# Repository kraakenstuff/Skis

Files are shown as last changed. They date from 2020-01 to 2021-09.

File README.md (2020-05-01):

# Skis

This is smd version of Bastl Skis v1. Main differences are:

* It has skis (two sliders) vs. no skis in Bastl version
* 6HP vs. 5HP, for obvious, OCD reasons
* Range switch vs. range backside jumper (although this switch works as a jumper - instead of going from freq0 to freq1, and then from freq1 to freq2 in the second position, it goes from freq0 to freq1, and then from freq0 to freq2)
* Version 2 of Bastl Skis has decay CV input, and this one doesn't have it
* Version 1 of Bastl Skis was THT and had two sandwiched boards, and this one is SMT in one board.

Status: tested and working.

CC-BY-SA
Václav Peloušek
bastl-instruments.com

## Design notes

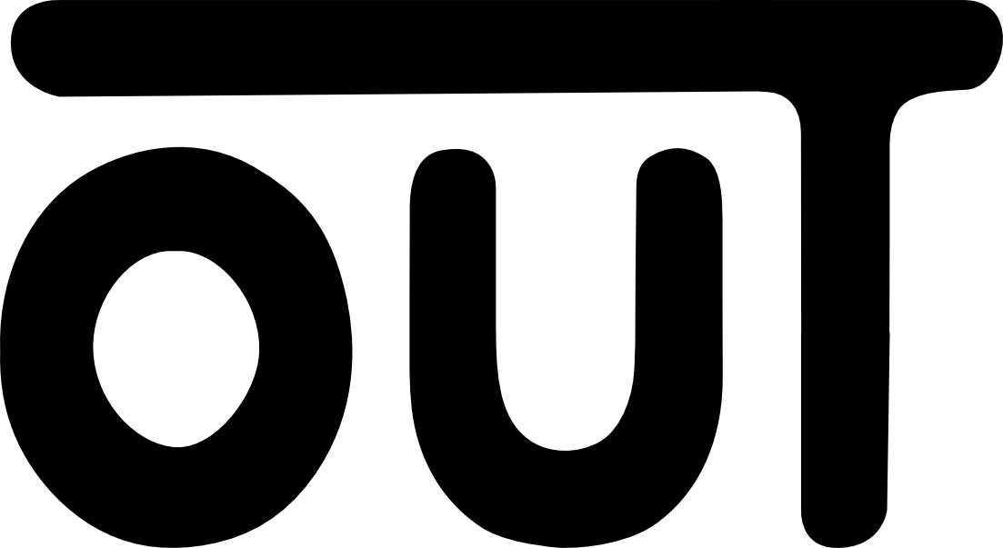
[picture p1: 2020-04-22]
art/out1.png

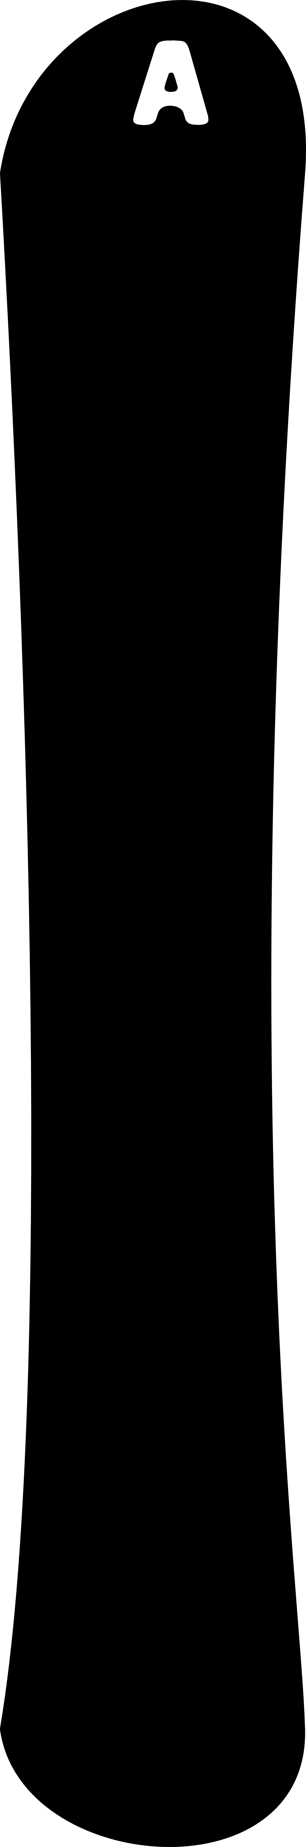
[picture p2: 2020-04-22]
art/ski_a.png

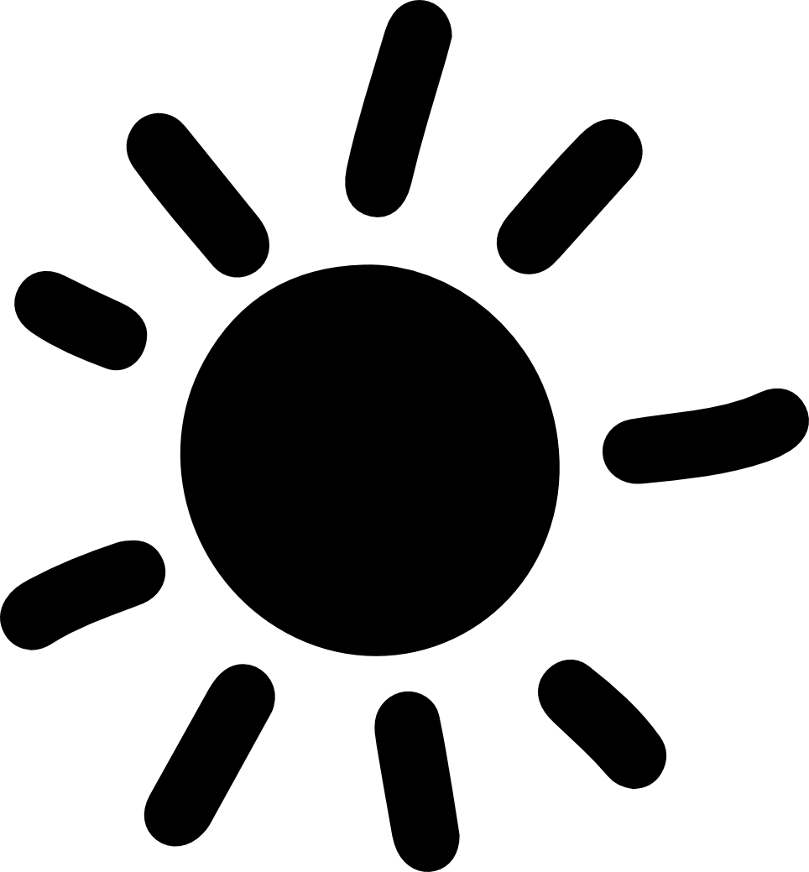
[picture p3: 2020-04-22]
art/sun.png

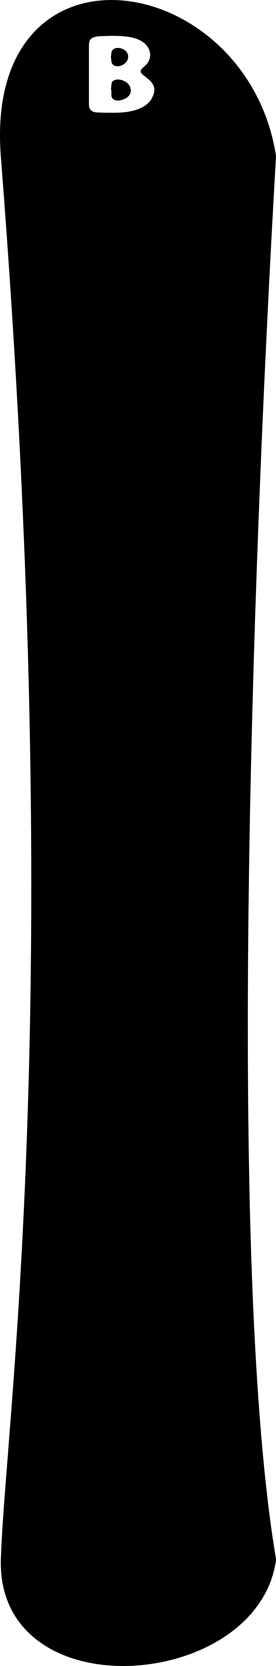
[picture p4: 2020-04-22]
art/ski_b.png

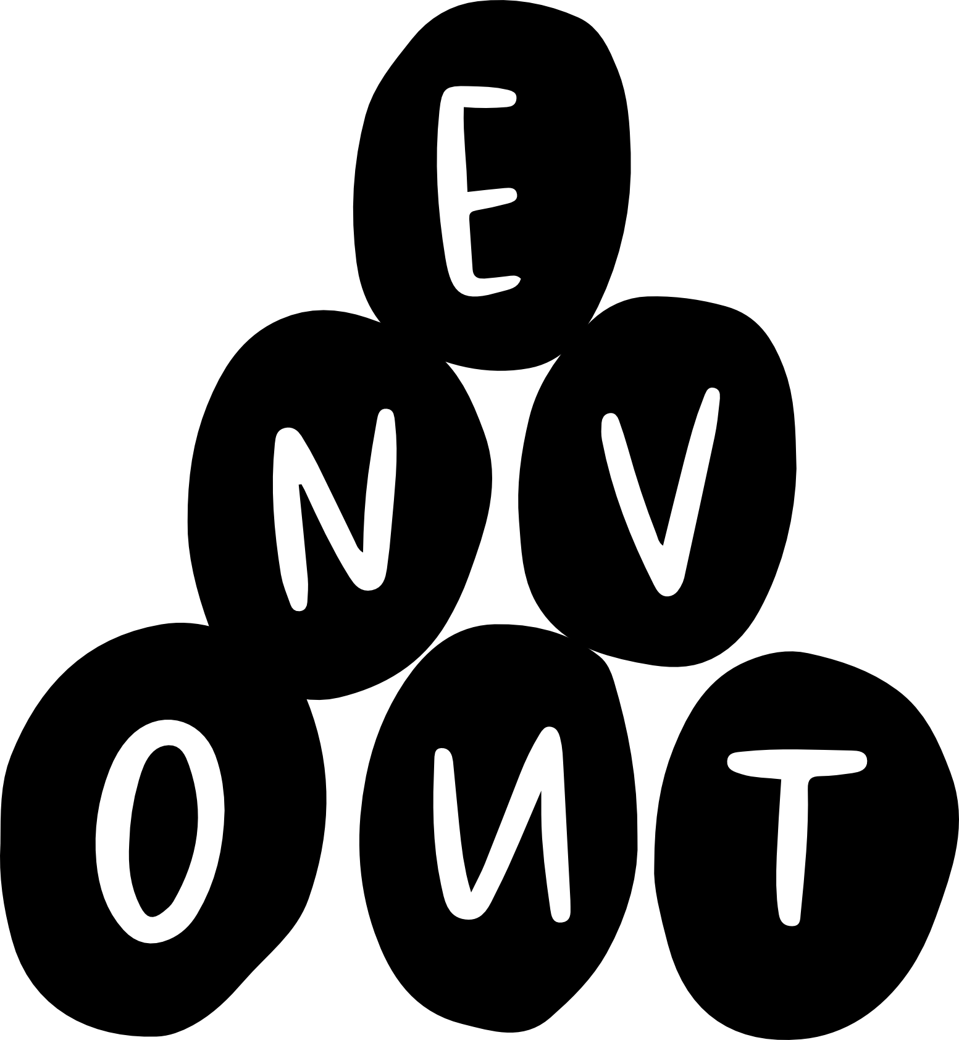
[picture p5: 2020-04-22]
art/env_out.png

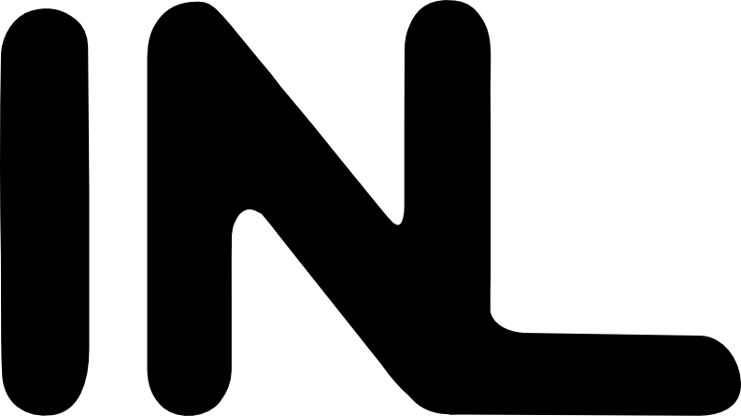
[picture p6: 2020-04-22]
art/in1.png

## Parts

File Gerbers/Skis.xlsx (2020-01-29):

Comment | Designator | Footprint
10n | C1,C2,C15,C16 | C_0603_1608Metric_Pad1.05x0.95mm_HandSolder
1u | C3,C17 | CP_Elec_4x5.8
10u | C4,C5,C6,C18 | CP_Elec_5x5.8
100n | C7,C8,C9,C10,C11,C12,C13,C14 | C_0603_1608Metric_Pad1.05x0.95mm_HandSolder
1N5819 | D3,D4 | D_SOD-123
BS170F | Q1,Q2,Q5,Q6,Q7,Q10 | SOT-23
MMBT3906 | Q3,Q8 | SOT-23
MMBT3904 | Q4,Q9 | SOT-23
100k | R1,R2,R5,R6,R8,R9,R15,R20,R21,R24,R25,R27,R28,R34 | R_0603_1608Metric_Pad1.05x0.95mm_HandSolder
1k | R3,R4,R10,R12,R13,R17,R18,R19,R22,R23,R29,R31,R32,R36,R37,R38 | R_0603_1608Metric_Pad1.05x0.95mm_HandSolder
10k | R7,R14,R26,R33 | R_0603_1608Metric_Pad1.05x0.95mm_HandSolder
47k | R11,R30 | R_0603_1608Metric_Pad1.05x0.95mm_HandSolder
4k7 | R16,R35 | R_0603_1608Metric_Pad1.05x0.95mm_HandSolder
TL074 | U1,U3 | SSOP-14_5.3x6.2mm_P0.65mm
LM13700 | U2 | SOIC-16W_5.3x10.2mm_P1.27mm
1N4148 | D5,D1 | D_0603_1608Metric_Pad1.05x0.95mm_HandSolder

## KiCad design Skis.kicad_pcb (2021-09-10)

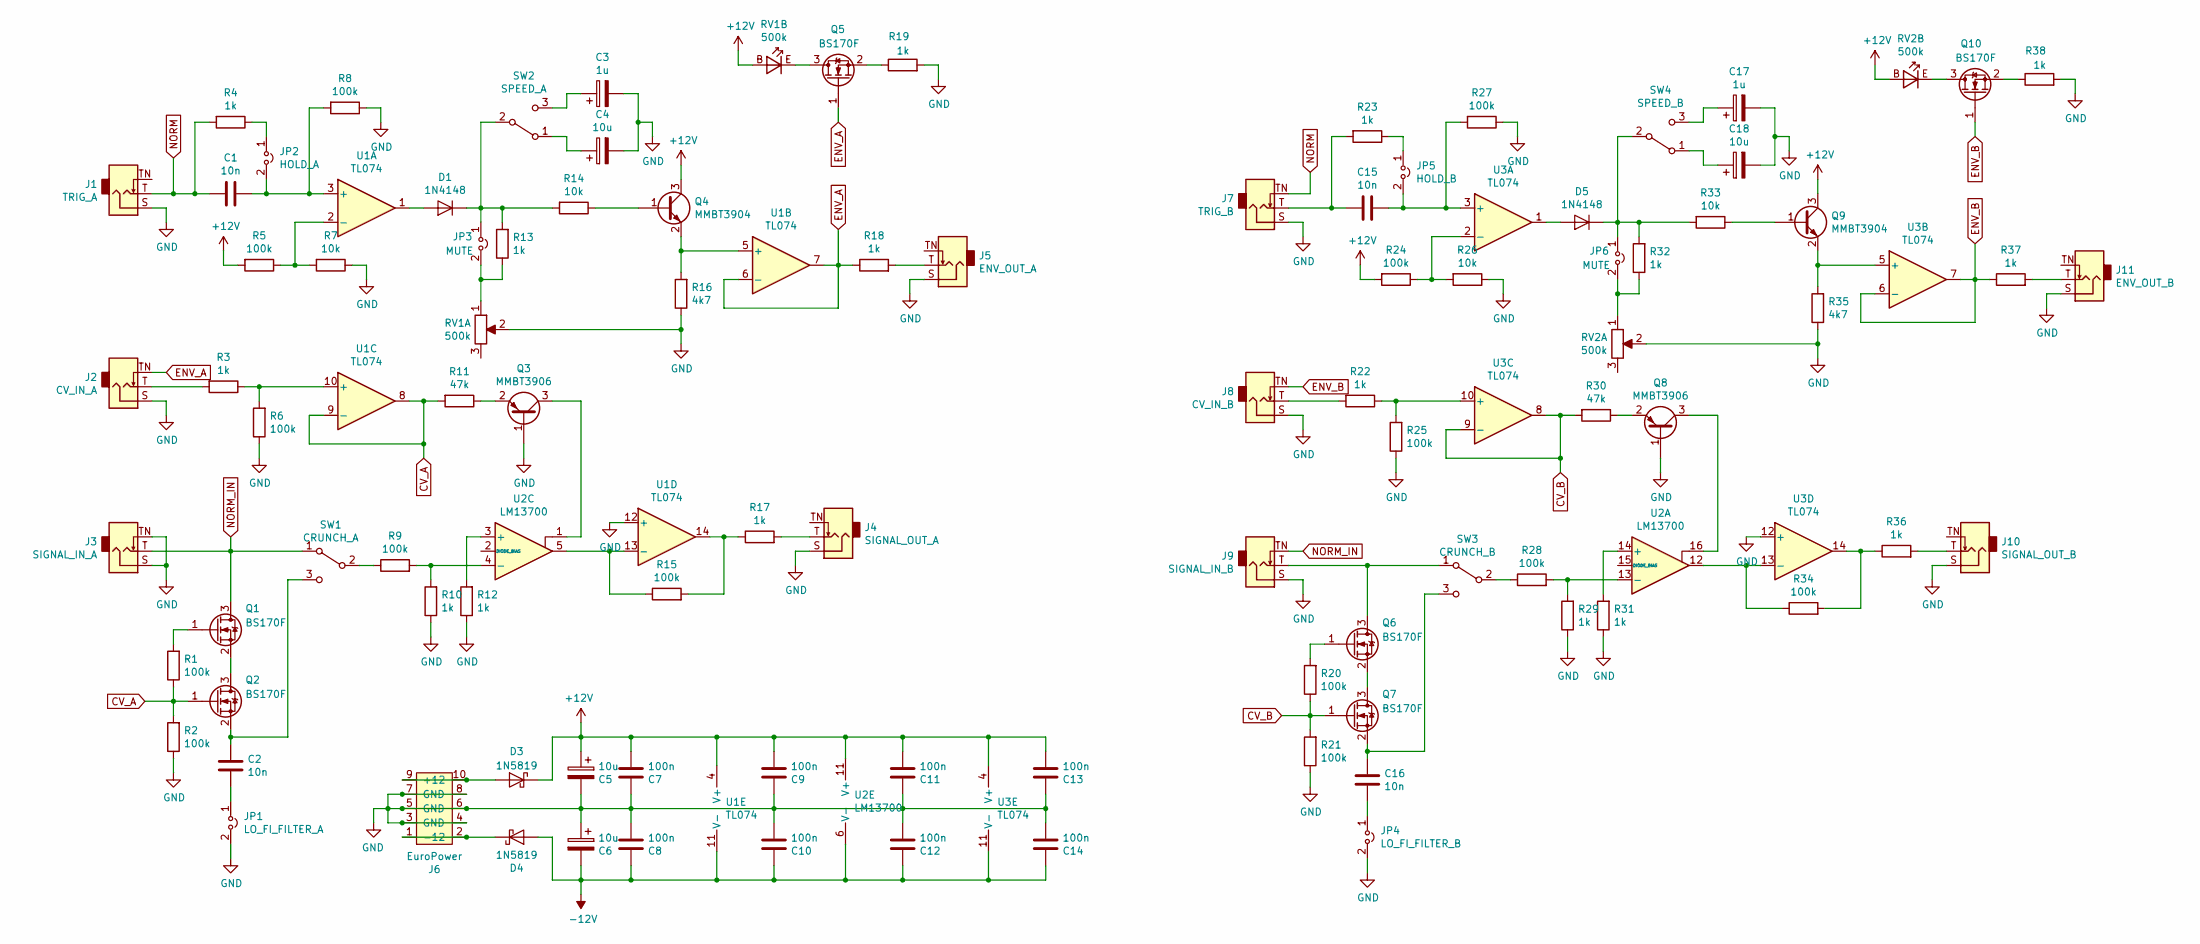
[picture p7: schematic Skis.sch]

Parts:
C1, C2, C15, C16: 10n; C_0603_1608Metric_Pad1.05x0.95mm_HandSolder
C3, C17: 1u; CP_Elec_4x5.8
C4, C5, C6, C18: 10u; CP_Elec_5x5.8
C7, C8, C9, C10, C11, C12, C13, C14: 100n; C_0603_1608Metric_Pad1.05x0.95mm_HandSolder
D1, D5: 1N4148; D_0603_1608Metric_Pad1.05x0.95mm_HandSolder
D3, D4: 1N5819; D_SOD-123
J1: TRIG_A; PJ301M-12-NoHole
J2: CV_IN_A; PJ301M-12-NoHole
J3: SIGNAL_IN_A; PJ301M-12-NoHole
J4: SIGNAL_OUT_A; PJ301M-12-NoHole
J5: ENV_OUT_A; PJ301M-12-NoHole
J6: EuroPower; EuroHeader10
J7: TRIG_B; PJ301M-12-NoHole
J8: CV_IN_B; PJ301M-12-NoHole
J9: SIGNAL_IN_B; PJ301M-12-NoHole
J10: SIGNAL_OUT_B; PJ301M-12-NoHole
J11: ENV_OUT_B; PJ301M-12-NoHole
JP1: LO_FI_FILTER_A; Header 1x2
JP2: HOLD_A; Header 1x2
JP3, JP6: MUTE; Header 1x2
JP4: LO_FI_FILTER_B; Header 1x2
JP5: HOLD_B; Header 1x2
Q1, Q2, Q5, Q6, Q7, Q10: BS170F; SOT-23
Q3, Q8: MMBT3906; SOT-23
Q4, Q9: MMBT3904; SOT-23
R1, R2, R5, R6, R8, R9, R15, R20, R21, R24, R25, R27, R28, R34: 100k; R_0603_1608Metric_Pad1.05x0.95mm_HandSolder
R3, R4, R10, R12, R13, R17, R18, R19, R22, R23, R29, R31, R32, R36, R37, R38: 1k; R_0603_1608Metric_Pad1.05x0.95mm_HandSolder
R7, R14, R26, R33: 10k; R_0603_1608Metric_Pad1.05x0.95mm_HandSolder
R11, R30: 47k; R_0603_1608Metric_Pad1.05x0.95mm_HandSolder
R16, R35: 4k7; R_0603_1608Metric_Pad1.05x0.95mm_HandSolder
RV1, RV2: 500k; PTL30
SW1: CRUNCH_A; SubSwitch_SPDT
SW2: SPEED_A; SubSwitch_SPDT
SW3: CRUNCH_B; SubSwitch_SPDT
SW4: SPEED_B; SubSwitch_SPDT
U1, U3: TL074; SSOP-14_5.3x6.2mm_P0.65mm
U2: LM13700; SOIC-16W_5.3x10.2mm_P1.27mm

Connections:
+12V: C5.1, C7.1, C9.1, C11.1, C13.1, D3.1 (K), Q4.3 (C), Q9.3 (C), R5.2, R24.2, RV1.B, RV2.B, U1.4 (V+), U2.11 (V+), U3.4 (V+)
-12V: C6.2, C8.2, C10.2, C12.2, C14.2, D4.2 (A), U1.11 (V-), U2.6 (V-), U3.11 (V-)
CV_A: Q2.1 (G), R1.1, R2.2, R11.2, U1.8, U1.9 (-)
CV_B: Q7.1 (G), R20.1, R21.2, R30.2, U3.8, U3.9 (-)
ENV_A: J2.TN, Q5.1 (G), R18.1, U1.6 (-), U1.7
ENV_B: J8.TN, Q10.1 (G), R37.1, U3.6 (-), U3.7
GND: C3.2, C4.2, C5.2, C6.1, C7.2, C8.1, C9.2, C10.1, C11.2, C12.1, C13.2, C14.1, C17.2, C18.2, J1.S, J2.S, J3.S, J3.TN, J4.S, J5.S, J6.3 (GND), J6.4, J6.5 (GND), J6.6, J6.7 (GND), J6.8, J7.S, J8.S, J9.S, J10.S, J11.S, JP1.2, JP4.2, Q3.1 (B), Q8.1 (B), R2.1, R6.1, R7.1, R8.1, R10.1, R12.1, R16.1, R19.2, R21.1, R25.1, R26.1, R27.1, R29.1, R31.1, R35.1, R38.2, RV1.2, RV2.2, U1.12 (+), U3.12 (+)
NORM: C1.2, J1.T, J7.TN, R4.2
NORM_IN: J3.T, J9.TN, Q1.3 (D), SW1.1 (A)
unnamed: C1.1, JP2.2, R8.2, U1.3 (+)
unnamed: C2.1, JP1.1
unnamed: C2.2, Q2.2 (S), SW1.3 (C)
unnamed: C3.1, SW2.3 (C)
unnamed: C4.1, SW2.1 (A)
unnamed: C15.1, JP5.2, R27.2, U3.3 (+)
unnamed: C15.2, J7.T, R23.2
unnamed: C16.1, JP4.1
unnamed: C16.2, Q7.2 (S), SW3.3 (C)
unnamed: C17.1, SW4.3 (C)
unnamed: C18.1, SW4.1 (A)
unnamed: D1.1 (K), JP3.1, R13.2, R14.2, SW2.2 (B)
unnamed: D1.2 (A), U1.1
unnamed: D3.2 (A), J6.9 (+12), J6.10
unnamed: D4.1 (K), J6.1 (-12), J6.2
unnamed: D5.1 (K), JP6.1, R32.2, R33.2, SW4.2 (B)
unnamed: D5.2 (A), U3.1
unnamed: J2.T, R3.2
unnamed: J4.T, R17.2
unnamed: J5.T, R18.2
unnamed: J8.T, R22.2
unnamed: J9.T, Q6.3 (D), SW3.1 (A)
unnamed: J10.T, R36.2
unnamed: J11.T, R37.2
unnamed: JP2.1, R4.1
unnamed: JP3.2, R13.1, RV1.1
unnamed: JP5.1, R23.1
unnamed: JP6.2, R32.1, RV2.1
unnamed: Q1.1 (G), R1.2
unnamed: Q1.2 (S), Q2.3 (D)
unnamed: Q3.2 (E), R11.1
unnamed: Q3.3 (C), U2.1
unnamed: Q4.1 (B), R14.1
unnamed: Q4.2 (E), R16.2, U1.5 (+)
unnamed: Q5.2 (S), R19.1
unnamed: Q5.3 (D), RV1.E
unnamed: Q6.1 (G), R20.2
unnamed: Q6.2 (S), Q7.3 (D)
unnamed: Q8.2 (E), R30.1
unnamed: Q8.3 (C), U2.16
unnamed: Q9.1 (B), R33.1
unnamed: Q9.2 (E), R35.2, U3.5 (+)
unnamed: Q10.2 (S), R38.1
unnamed: Q10.3 (D), RV2.E
unnamed: R3.1, R6.2, U1.10 (+)
unnamed: R5.1, R7.2, U1.2 (-)
unnamed: R9.1, SW1.2 (B)
unnamed: R9.2, R10.2, U2.4 (-)
unnamed: R12.2, U2.3 (+)
unnamed: R15.1, U1.13 (-), U2.5
unnamed: R15.2, R17.1, U1.14
unnamed: R22.1, R25.2, U3.10 (+)
unnamed: R24.1, R26.2, U3.2 (-)
unnamed: R28.1, SW3.2 (B)
unnamed: R28.2, R29.2, U2.13 (-)
unnamed: R31.2, U2.14 (+)
unnamed: R34.1, U2.12, U3.13 (-)
unnamed: R34.2, R36.1, U3.14

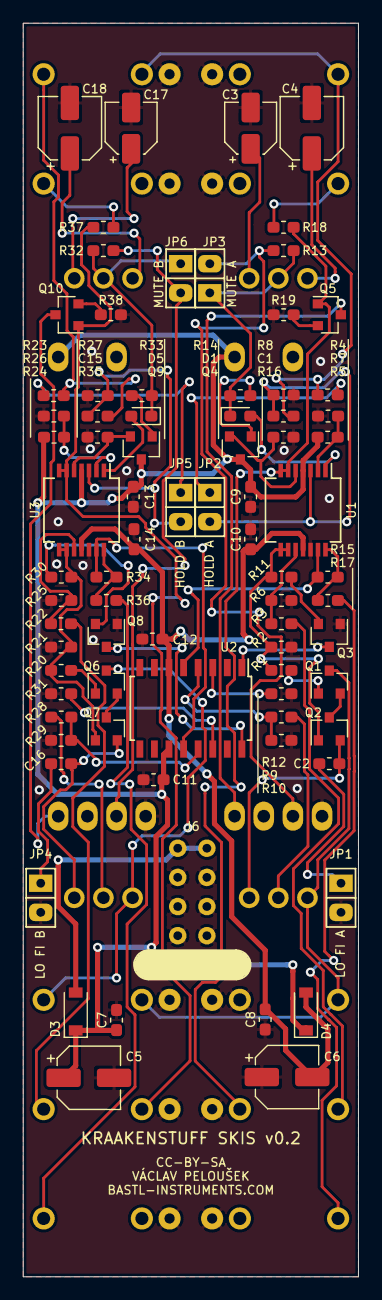
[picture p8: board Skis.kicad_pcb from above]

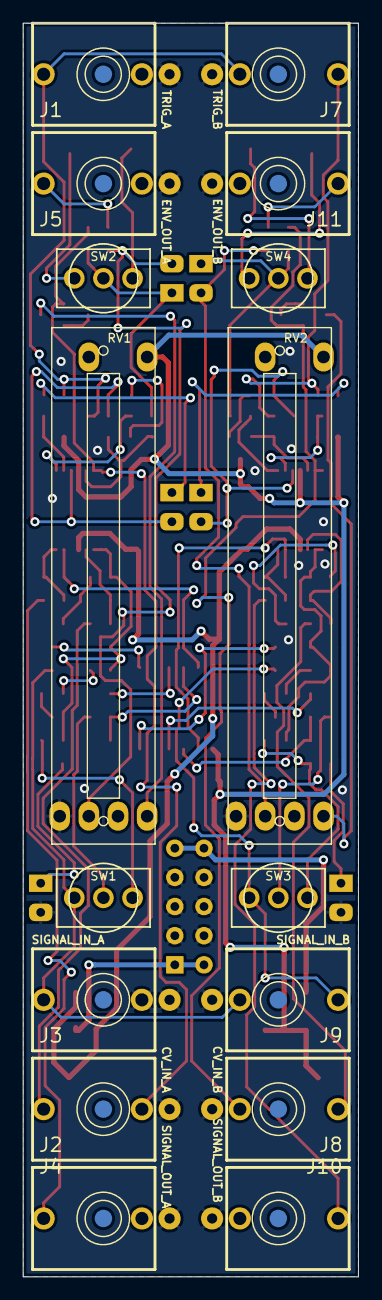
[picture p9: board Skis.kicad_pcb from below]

Board: 2 copper layers, 29.2 x 109.2 mm, 96 parts (16 on the bottom side), 67 nets.

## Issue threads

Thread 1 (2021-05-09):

Issue in the GerBer file

Yulquen, 2021-05-09:
Hi there,

In the GerBer file there is one hole missing between R17 and the output. See below

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

KeLaiFu, 2021-05-15:
Thanks for the heads up! Looks like I'll need to botch a wire, I've got a set of these on the bench at the mo. Seems to be fixed in the .pcb file.

KeLaiFu, 2021-05-20:
> yep, I had to do it:
>

Good to know that's all it needed, I was worried there may be other things amiss.

Since you finished the module, maybe you can solve the other issue I am having before starting this build: Which slide potentiometer did you use? I see in the kicad file it mentions the value being 500k, but here in China I cannot find any that are this value and 45mm, let alone ones with LEDs. The ones I am finding are much lower values, like 5 and 10k.

KeLaiFu, 2021-05-28:
The only 500k 45mm LED slide pots I can find are the Bournes PTL45-19G0-504B2, I can only get them imported in 10's here, which is a little expensive.

kraakenstuff, 2021-09-10:
Ugh! Sorry guys, looks like I didn't update npth files. Should be ok now.
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

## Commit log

2020-04-22 Added panel
    [Skis - panel-B_Cu.gbr, Skis - panel-B_Mask.gbr, Skis - panel-B_Paste.gbr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]
2020-04-23 Added normalization for input jacks
    [Skis.kicad_pcb, Skis.sch]
2020-04-23 Changed version number on pcb
    [Skis.kicad_pcb]
2020-04-23 Generated gerbers
    [Skis-B_Cu.gbr, Skis-B_Mask.gbr, Skis-B_Paste.gbr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]
2021-09-10 Recreated gerber files
    [Skis-B_Cu.gbr, Skis-B_Mask.gbr, Skis-B_Paste.gbr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]
